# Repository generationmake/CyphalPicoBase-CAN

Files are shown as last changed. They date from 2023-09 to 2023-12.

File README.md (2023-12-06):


CyphalPicoBase/CAN
==================
Board for the Raspberry Pi Pico to connect via CAN using OpenCyphal and UCANPHY Micro.

You can buy one [here](https://cyphal.store/products/lxrobotics-cyphalpicobase-can) 💸.

<p align="center">
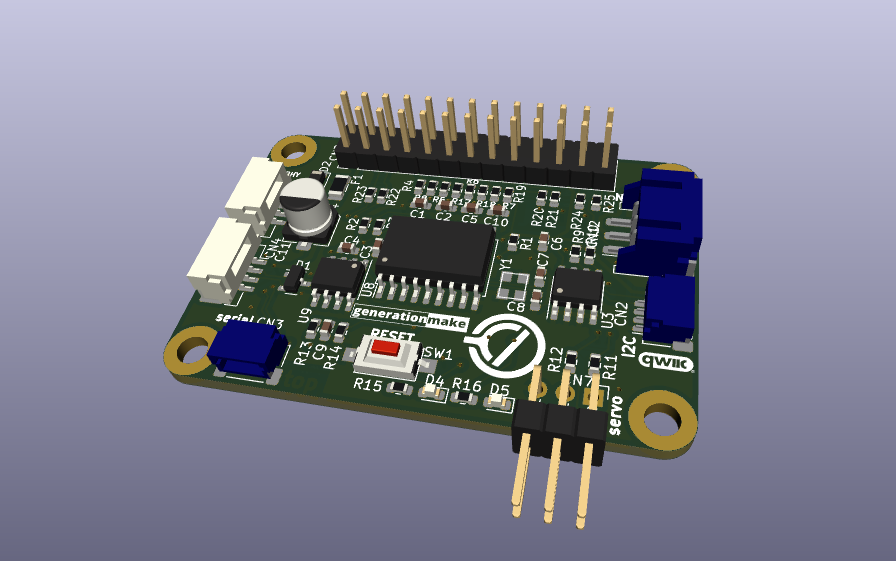
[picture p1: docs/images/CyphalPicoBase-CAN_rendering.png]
  
</p>

<p align="center">
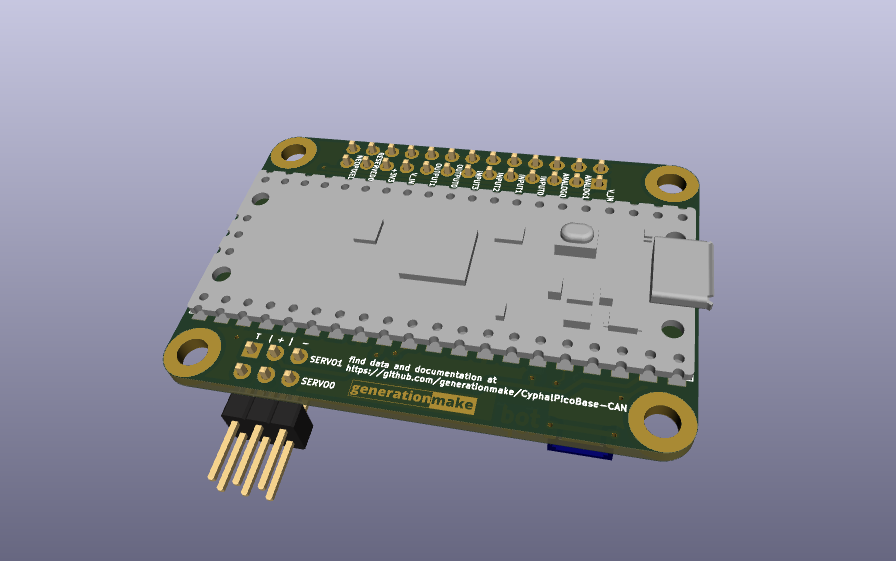
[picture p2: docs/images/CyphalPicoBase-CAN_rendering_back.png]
  
</p>

## Description

The CyphalPicoBase/CAN provides the following functions:
* CAN connectivity to a OpenCyphal CAN bus using a Microchip MCP2515 CAN controller ([datasheet](https://ww1.microchip.com/downloads/en/DeviceDoc/MCP2515-Stand-Alone-CAN-Controller-with-SPI-20001801J.pdf))
* Onboard I2C EEPROM to store settings
* measurement of CAN bus voltage using GP26
* onboard temperature measurement using the internal temperature sensor of the Raspberry Pi Pico
* two status LEDs (D4 and D5)
* Raspberry Pi Pico directly mounted on bottom layer
* connectors to several external functions (see list below)

## Firmware
* [CyphalPicoBase-CAN-firmware](https://github.com/107-systems/CyphalPicoBase-CAN-firmware): This is the default firmware for this board. It enables all basic functions

## Pin Usage and connectors

<p align="center">
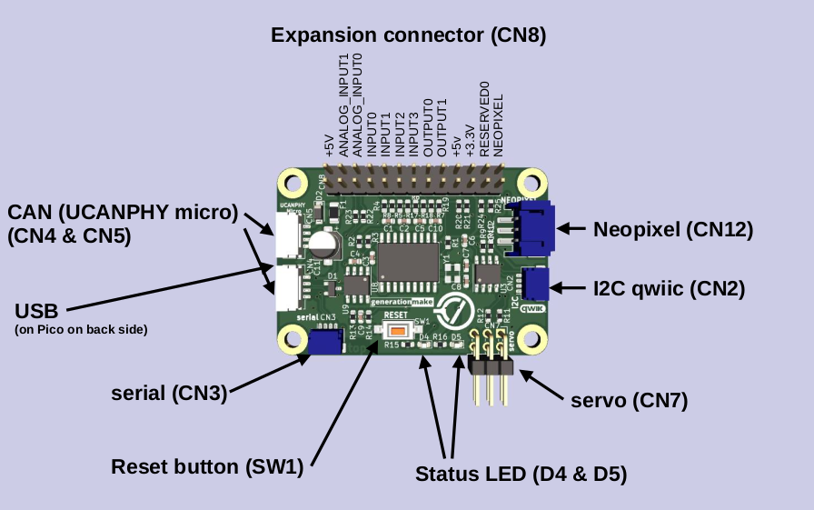
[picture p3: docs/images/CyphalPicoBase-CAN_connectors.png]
  
</p>

### Raspberry Pi Pico (CN1)

| **Pin** | **Pin Name** | **Signal** | **Description** |
|:---:|:---:|:---:|:---:|
| 1 | GP0 | UART0_TX | reserved for future use (GNSS) |
| 2 | GP1 | UART0_RX | reserved for future use (GNSS) |
| 3 | GND | GND | |
| 4 | GP2 | | |
| 5 | GP3 | | |
| 6 | GP4 | I2C0_SDA | for eeprom and qwiic connector |
| 7 | GP5 | I2C0_SCL | for eeprom and qwiic connector |
| 8 | GND | GND | |
| 9 | GP6 | GPI0 | input 0 |
| 10 | GP7 | GPI1 | input 1 |
| 11 | GP8 | GPI2 | input 2 |
| 12 | GP9 | GPI3 | input 3 |
| 13 | GND | GND | |
| 14 | GP10 | GPO0 | output 0 |
| 15 | GP11 | GPO1 | output 1 |
| 16 | GP12 | reserved | Neopixel |
| 17 | GP13 | reserved | radiation detector |
| 18 | GND | GND | |
| 19 | GP14 | SERVO0 | servo 0 |
| 20 | GP15 | SERVO1 | servo 1 |
| 21 | GP16 | SPI_MISO | SPI for MCP2515 |
| 22 | GP17 | MCP2515_CS | SPI for MCP2515 |
| 23 | GND | GND | |
| 24 | GP18 | SPI_CLK | SPI for MCP2515 |
| 25 | GP19 | SPI_MOSI | SPI for MCP2515 |
| 26 | GP20 | MCP2515_INT | interrupt for MCP2515 |
| 27 | GP21 | STATUS_LED2 | internal status LED 2 |
| 28 | GND | GND | |
| 29 | GP22 | STATUS_LED3 | internal status LED 3 |
| 30 | RUN | RESET | Reset for Board |
| 31 | GP26 | INPUT_VOLTAGE | measure input voltage |
| 32 | GP27 | ANALOG_INPUT0 | analog input |
| 33 | GND | GND | |
| 34 | GP28 | ANALOG_INPUT1 | analog input |
| 35 | ADC_VREF | | |
| 36 | 3V3 (OUT) | 3V3-rail | supply voltage for board |
| 37 | 3V3_EN | | |
| 38 | GND | GND | |
| 39 | VSYS | | |
| 40 | VBUS | 5V-rail | supply voltage for board |

## Pinout

### I2C (CN2)

compatible to the Sparkfun qwiic standard (https://www.sparkfun.com/qwiic). JST SH 1mm 4-pin.

| pin number | signal |
|:---:|:---:|
| 1 | GND |
| 2 | +3V3 |
| 3 | I2C_SDA |
| 4 | I2C_SCL |

### serial (CN3)

JST SH 1mm 4-pin.

| pin number | signal |
|:---:|:---:|
| 1 | GND |
| 2 | +3V3 |
| 3 | SER_TX |
| 4 | SER_RX |

### CAN (CN4 and CN5)

UCANPHY Micro connector, according to the UCANPHY_Specification (https://forum.opencyphal.org/t/cyphal-can-physical-layer-specification-v1-0/1471). JST GH 1.25mm 4-pin.

| pin number | signal |
|:---:|:---:|
| 1 | +5V |
| 2 | CANH |
| 3 | CANL |
| 4 | GND |

### servo connector (CN7)

This is a regular 0.1-inch pin header.

Standard RC servos can be directly plugged into this connector

| pin number | signal |
|:---:|:---:|
| 1 | servo0 |
| 2 | servo1 |
| 3 | +5V |
| 4 | +5V |
| 5 | GND |
| 6 | GND |

### input/output connector (CN8)

This is a regular 0.1-inch pin header.

| pin number | signal |
|:---:|:---:|
| 1 | +5V |
| 2 | GND |
| 3 | ANALOG_INPUT1 |
| 4 | GND |
| 5 | ANALOG_INPUT0 |
| 6 | GND |
| 7 | INPUT0 |
| 8 | GND |
| 9 | INPUT1 |
| 10 | GND |
| 11 | INPUT2 |
| 12 | GND |
| 13 | INPUT3 |
| 14 | GND |
| 15 | OUTPUT0 |
| 16 | GND |
| 17 | OUTPUT1 |
| 18 | GND |
| 19 | +5V |
| 20 | GND |
| 21 | +3.3V |
| 22 | GND |
| 23 | RESERVED0 |
| 24 | GND |
| 25 | NEOPIXEL |
| 26 | GND |

+5V can be fed over this connector to the servo connector (CN7) and the neopixel connector (CN12) if power supply over the CAN connector is not sufficicant.

### neopixel connector (CN12)

connector for Adafruit Neopixel RGB leds (https://learn.adafruit.com/adafruit-neopixel-uberguide/the-magic-of-neopixels). JST PH 2mm 3-pin.

| pin number | signal |
|:---:|:---:|
| 1 | neopixel |
| 2 | +5V |
| 3 | GND |

## enclosure

There exists a 3D printable enclosure to encapsulate the PCB.

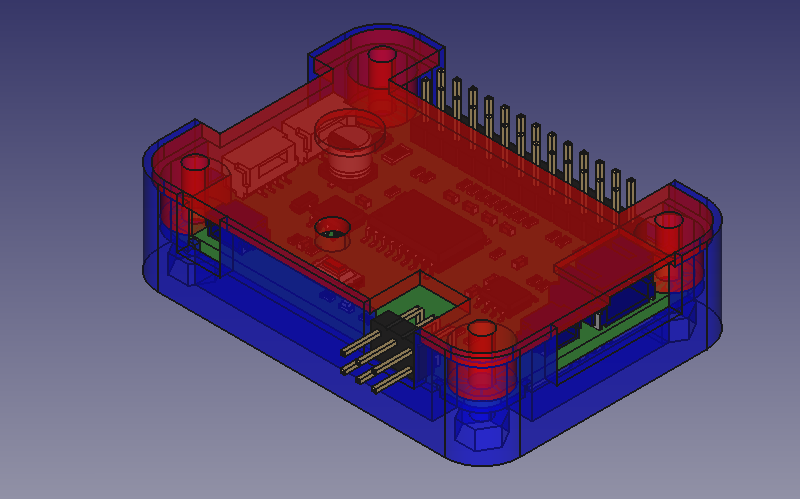
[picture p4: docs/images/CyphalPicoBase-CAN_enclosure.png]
CyphalPicoBase-CAN enclosure


## PCB
### Top
<p align="center">
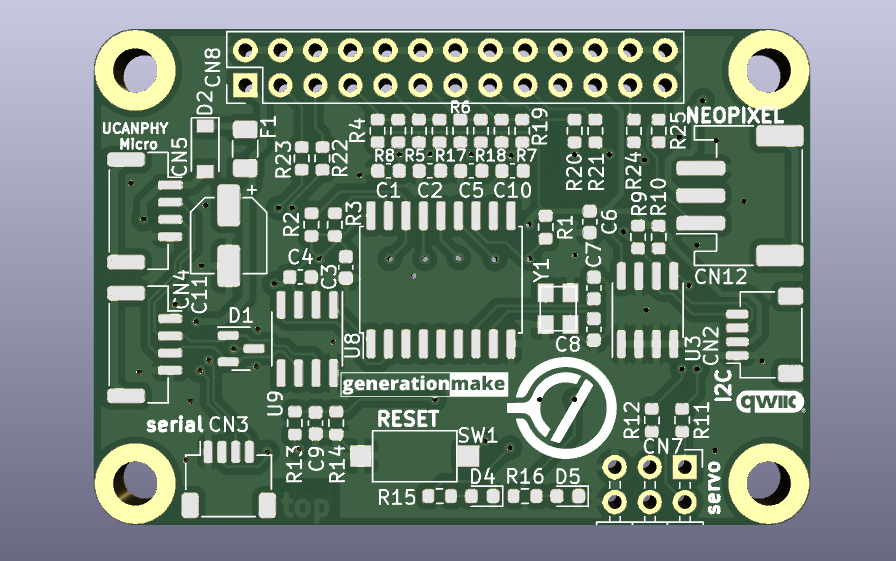
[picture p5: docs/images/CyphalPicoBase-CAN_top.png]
  
</p>

### Bottom
<p align="center">
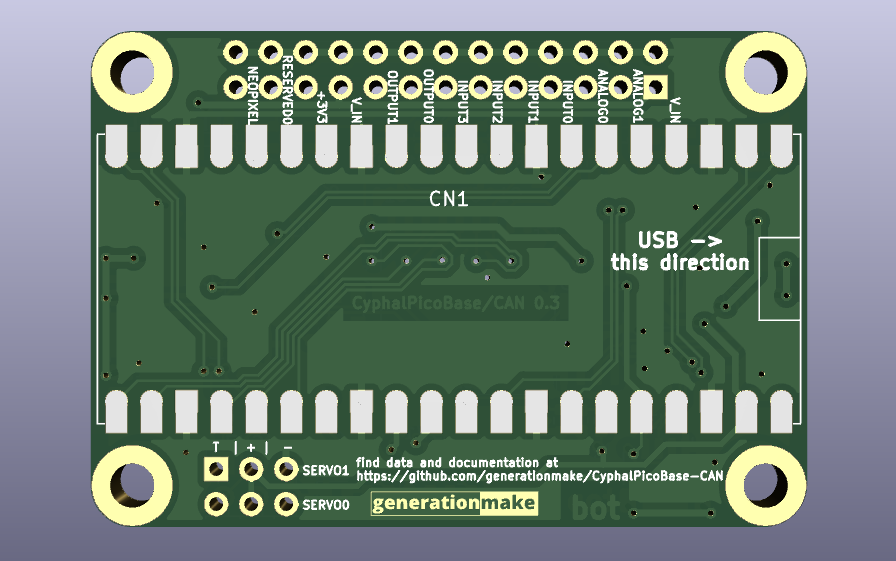
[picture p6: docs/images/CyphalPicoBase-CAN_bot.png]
  
</p>

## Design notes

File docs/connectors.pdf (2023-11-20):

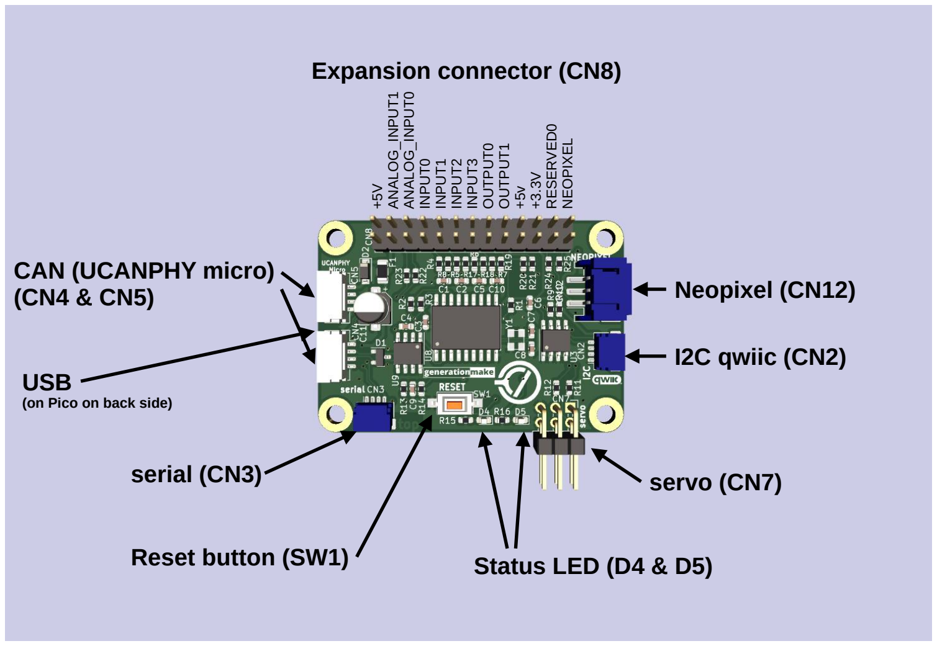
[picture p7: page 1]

Neopixel (CN12)

I2C qwiic (CN2)

CAN (UCANPHY micro)
(CN4 & CN5)

serial (CN3)

Reset button (SW1)

servo (CN7)

Status LED (D4 & D5)

USB

(on Pico on back side)

Expansion connector (CN8)

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
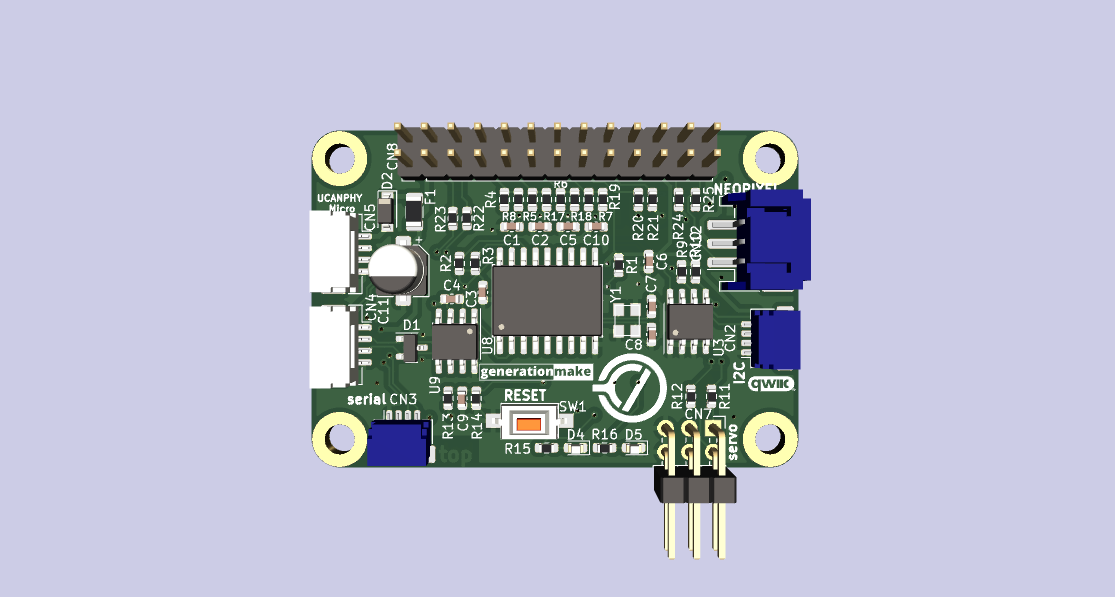
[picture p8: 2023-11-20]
docs/images/CyphalPicoBase-CAN_rendering_top.png

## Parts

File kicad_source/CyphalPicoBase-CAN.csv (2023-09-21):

Comment | Designator | Footprint | LCSC
100nF | C1,C2,C3,C4,C5,C6,C9,C10 | Capacitor_SMD:C_0603_1608Metric | C14663
100 uF / 6,3 V | C11 | Capacitor_SMD:CP_Elec_5x5.3 | C3001204
S3B-PH-SM4-TB | CN12 | Connector_JST:JST_PH_S3B-PH-SM4-TB_1x03-1MP_P2.00mm_Horizontal | C265101
SM04B-SRSS-TB | CN2,CN3 | Connector_JST:JST_SH_SM04B-SRSS-TB_1x04-1MP_P1.00mm_Horizontal | C160404
SM04B-GHS-TB | CN4,CN5 | Connector_JST:JST_GH_SM04B-GHS-TB_1x04-1MP_P1.25mm_Horizontal | C189895
MBR0530T | D2 | Diode_SMD:D_SOD-123 | C77336
NCD0603Y1 | D4 | LED_SMD:LED_0603_1608Metric | C84268
KT-0603R | D5 | LED_SMD:LED_0603_1608Metric | C2286
nSMD050-33V | F1 | Fuse:Fuse_1206_3216Metric | C70077
100R | R11,R12,R20,R21,R22,R23,R24,R25 | Resistor_SMD:R_0603_1608Metric | C22775
100k | R13 | Resistor_SMD:R_0603_1608Metric | C25803
3k3 | R15,R16 | Resistor_SMD:R_0603_1608Metric | C22978
10k | R1,R2,R3,R4,R5,R6,R7,R8,R9,R10,R14,R17,R18,R19 | Resistor_SMD:R_0603_1608Metric | C25804
PTS636 SM43 SMTR LFS | SW1 | Button_Switch_SMD:SW_SPST_CK_RS282G05A3 | C2800965
M24C64-RMN6TP | U3 | Package_SO:SOIC-8_3.9x4.9mm_P1.27mm | C79988
MCP2515T-I/SO | U8 | Package_SO:SOIC-18W_7.5x11.6mm_P1.27mm | C153782
SN65HVD230 | U9 | Package_SO:SOIC-8_3.9x4.9mm_P1.27mm | C12084
X322516MLB4SI | Y1 | crystals:Crystal_SMD_3.2x2.5mm_4Pad | C13738

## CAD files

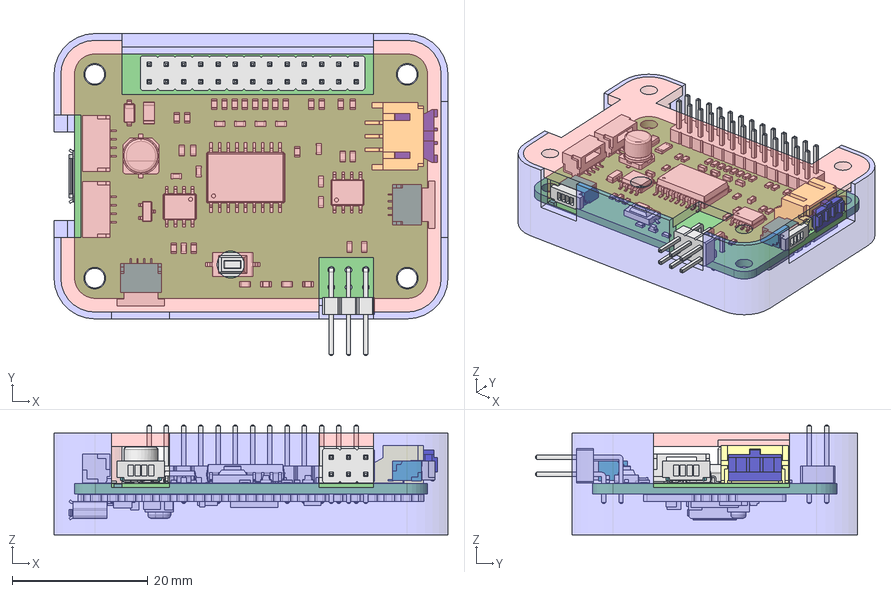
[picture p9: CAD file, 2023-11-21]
freecad_source/enclosure.FCStd
58.0 x 47.4 x 16.2 mm
bottom
top
CyphalPicoBase-CAN PCB
SHR-04V-S-B
SHR-04V-S-B001
PHR-3

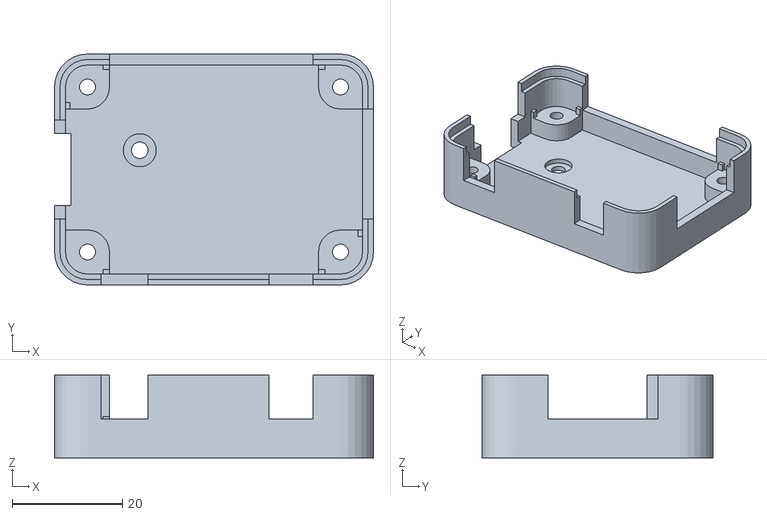
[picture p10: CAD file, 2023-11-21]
production_data/enclosure-bottom.stl
58.0 x 42.0 x 15.0

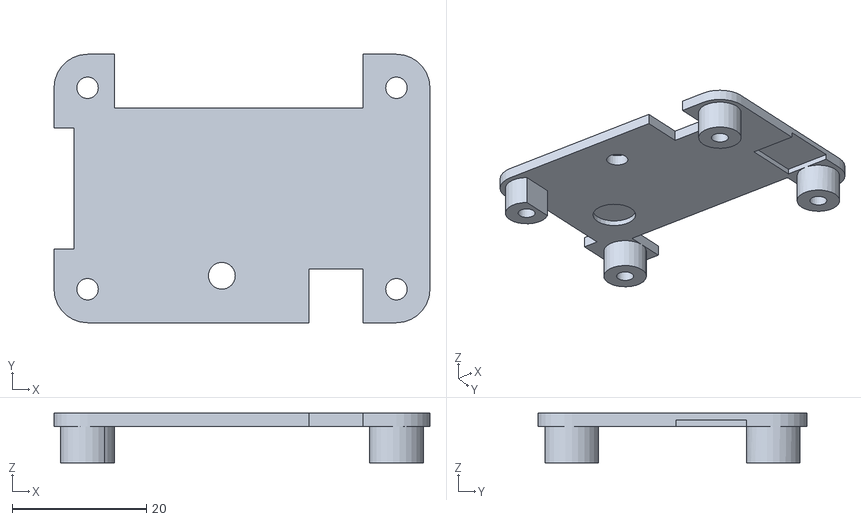
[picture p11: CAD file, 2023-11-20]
production_data/enclosure-top.stl
56.0 x 40.0 x 7.40

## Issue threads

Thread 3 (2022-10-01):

switch to SMD parts

generationmake, 2022-10-01:
switch to SMD parts for MCP2515 and crystal.
also switch to direct mounting of Raspberry Pi Pico. take care of the USB connector and place it on the edge of the board.

Closed 2023-01-04.

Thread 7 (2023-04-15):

add protection to CAN

generationmake, 2023-04-15:
Add some ESD protection to CAN bus.
For example with PESD2CAN on data lines.
https://assets.nexperia.com/documents/data-sheet/PESD2CAN.pdf
and TVS diode on bus voltage.

aentinger, 2023-04-16:
Let's discuss that. At one of my previous employers PESD2CAM added an unacceptable capacitance on the bus. Ultimately we got rid of them.

Closed 2023-09-21.

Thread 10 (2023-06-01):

Increase height of stand-offs inside bottom case by 1 mm to prevent BOOTSEL from accidentially being pressed

aentinger, 2023-06-01:
Adjust the rest of the design accordingly!

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

generationmake, 2023-06-01:
different approach: reduce thickness of the bottom plate in the area of the button by 1mm.

aentinger, 2023-06-02:
But make the area spacey enough, as any negative space always gets smaller during actual printing.

aentinger, 2023-06-04:
On further consideration: just increase the diameter of the already existing hole .

Closed 2023-06-18.

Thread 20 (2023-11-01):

[Feature Request] Replace SW1 w/ version w/ larger footprint

aentinger, 2023-11-01:
JLCPCB: C318938
https://jlcpcb.com/partdetail/XkbConnectivity-TS_1101_CW/C318938

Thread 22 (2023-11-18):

Feature Request: add cut-out for neopixel connector

aentinger, 2023-11-18:
Report by a customer:

I printed the CyphalPicoBase/CAN enclosure (using the file from GitHub) and the cover won't close, as the Neopixel connector is too tall for the cover spacers. You need to make a cut for the connector, I guess.

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

aentinger, 2023-11-18:
Or alternatively...

> A cut in the cover to allow the Neopixel to protrude somewhat into the cover, OR make spacers about 1 mm longer and increase the height of side walls of the enclosure by that same 1 mm.

Closed 2023-11-20.

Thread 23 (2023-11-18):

Feature Request: trim spacer on side of serial connector

aentinger, 2023-11-18:
Report by customer:

also, the cover spacer on the side of the serial connector is way too wide, so it's basically conflicting for space with the serial connector - would be good to trim the side of the spacer adjacent to the connector.

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

Closed 2023-11-20.

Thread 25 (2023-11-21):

[Feature Request] Increase size of outlet for Serial connector

aentinger, 2023-11-21:
Report by customer:

>Serial port hole is too narrow, connector won't fit through, I had to take the board pit, click it in, then put it back in.

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

Closed 2023-11-21.

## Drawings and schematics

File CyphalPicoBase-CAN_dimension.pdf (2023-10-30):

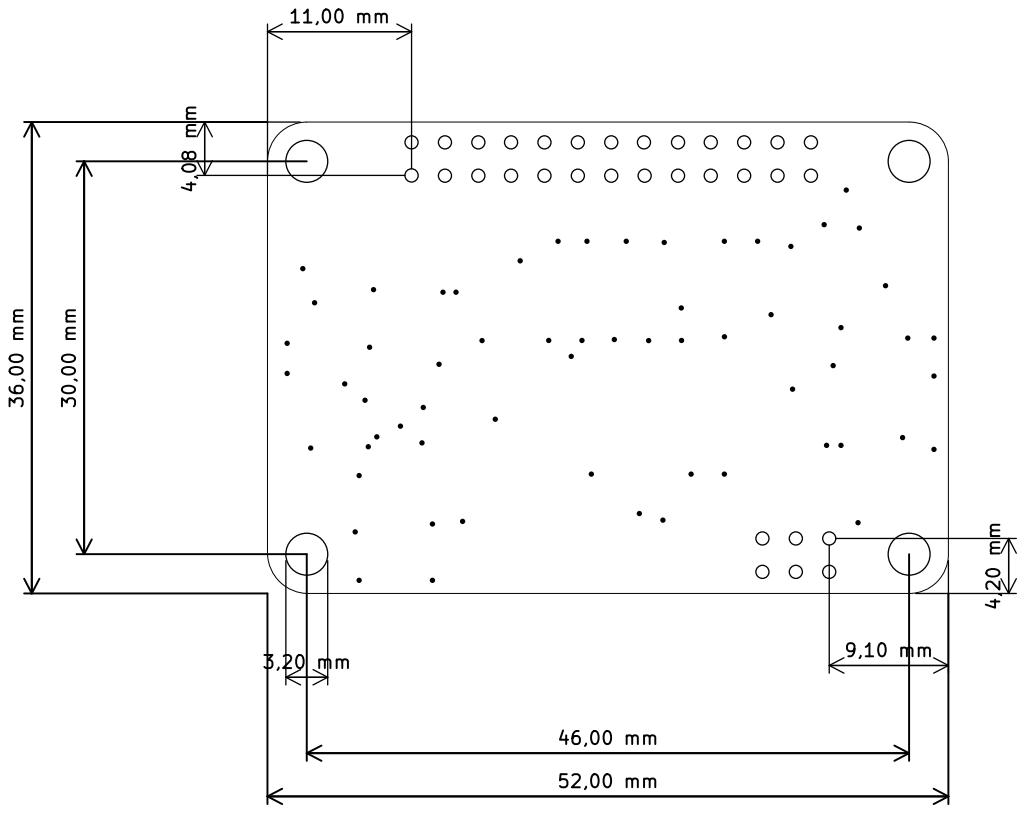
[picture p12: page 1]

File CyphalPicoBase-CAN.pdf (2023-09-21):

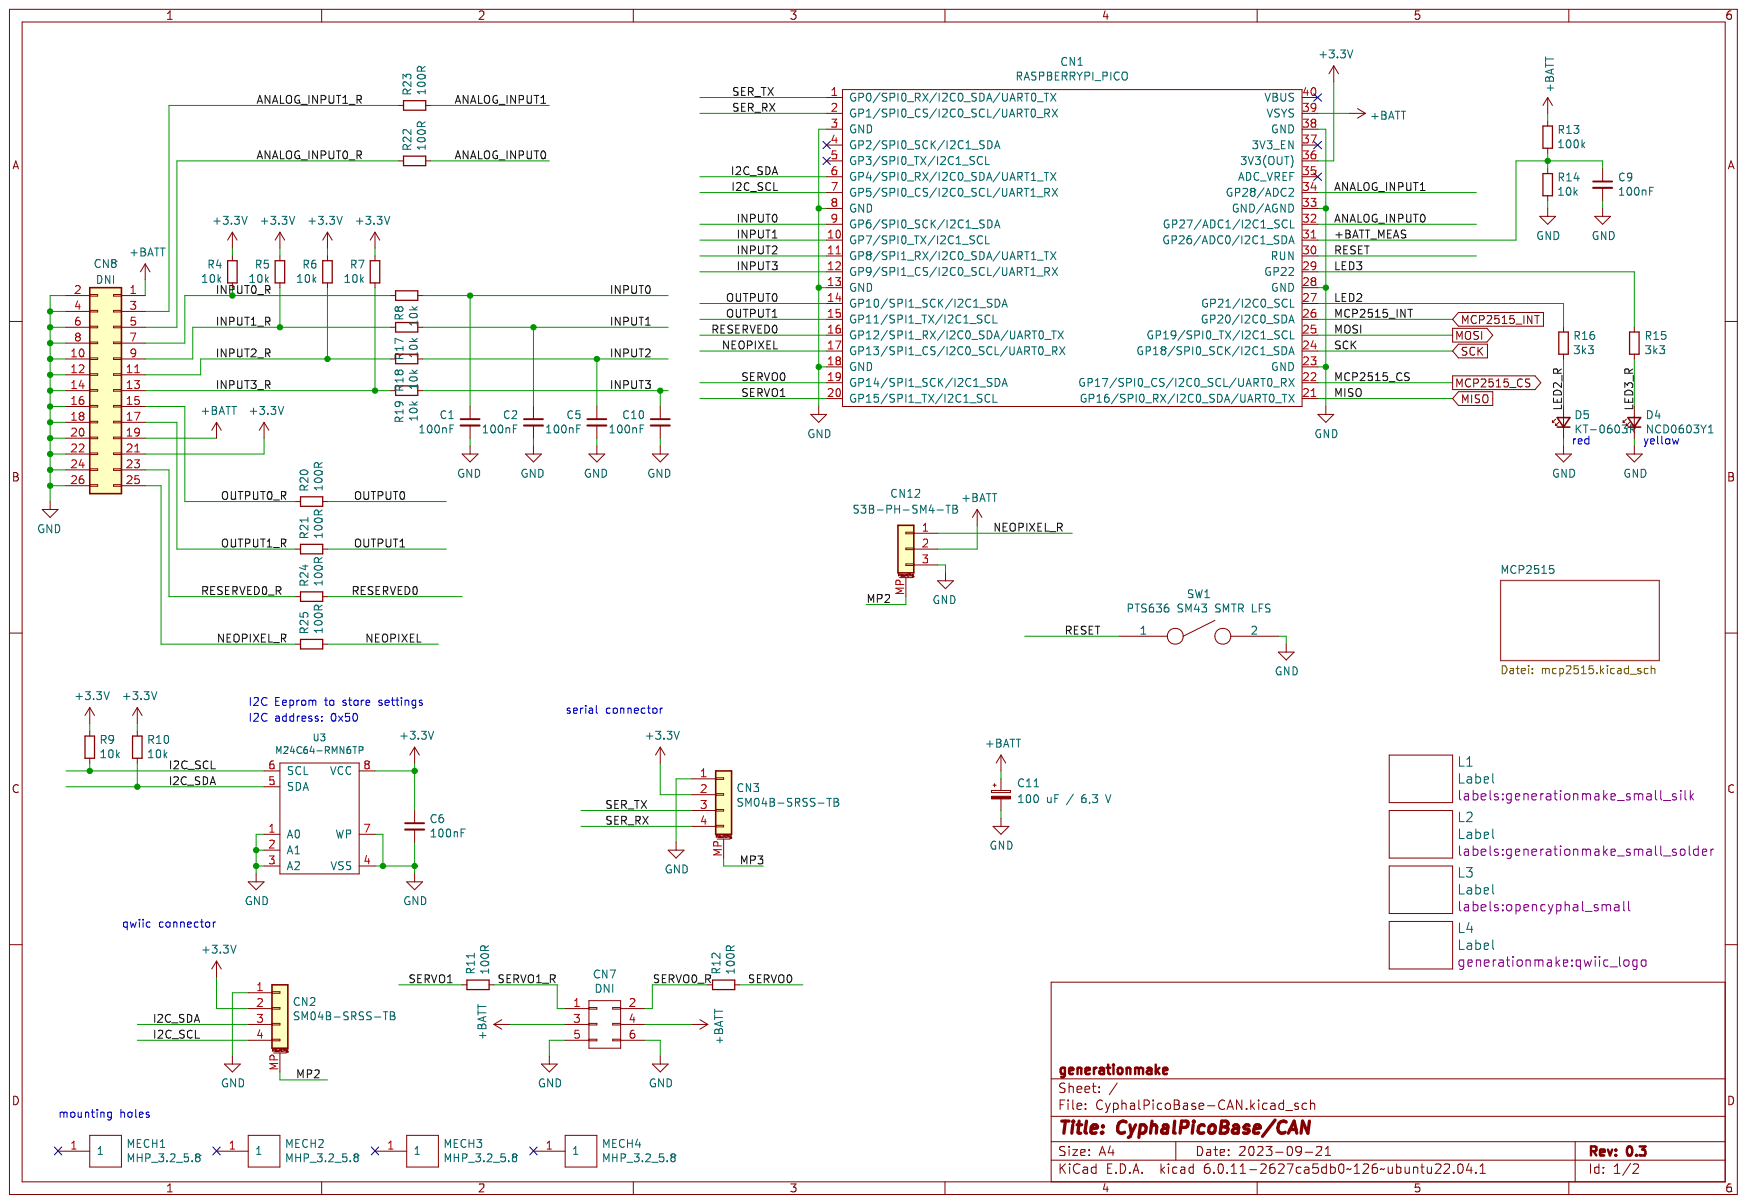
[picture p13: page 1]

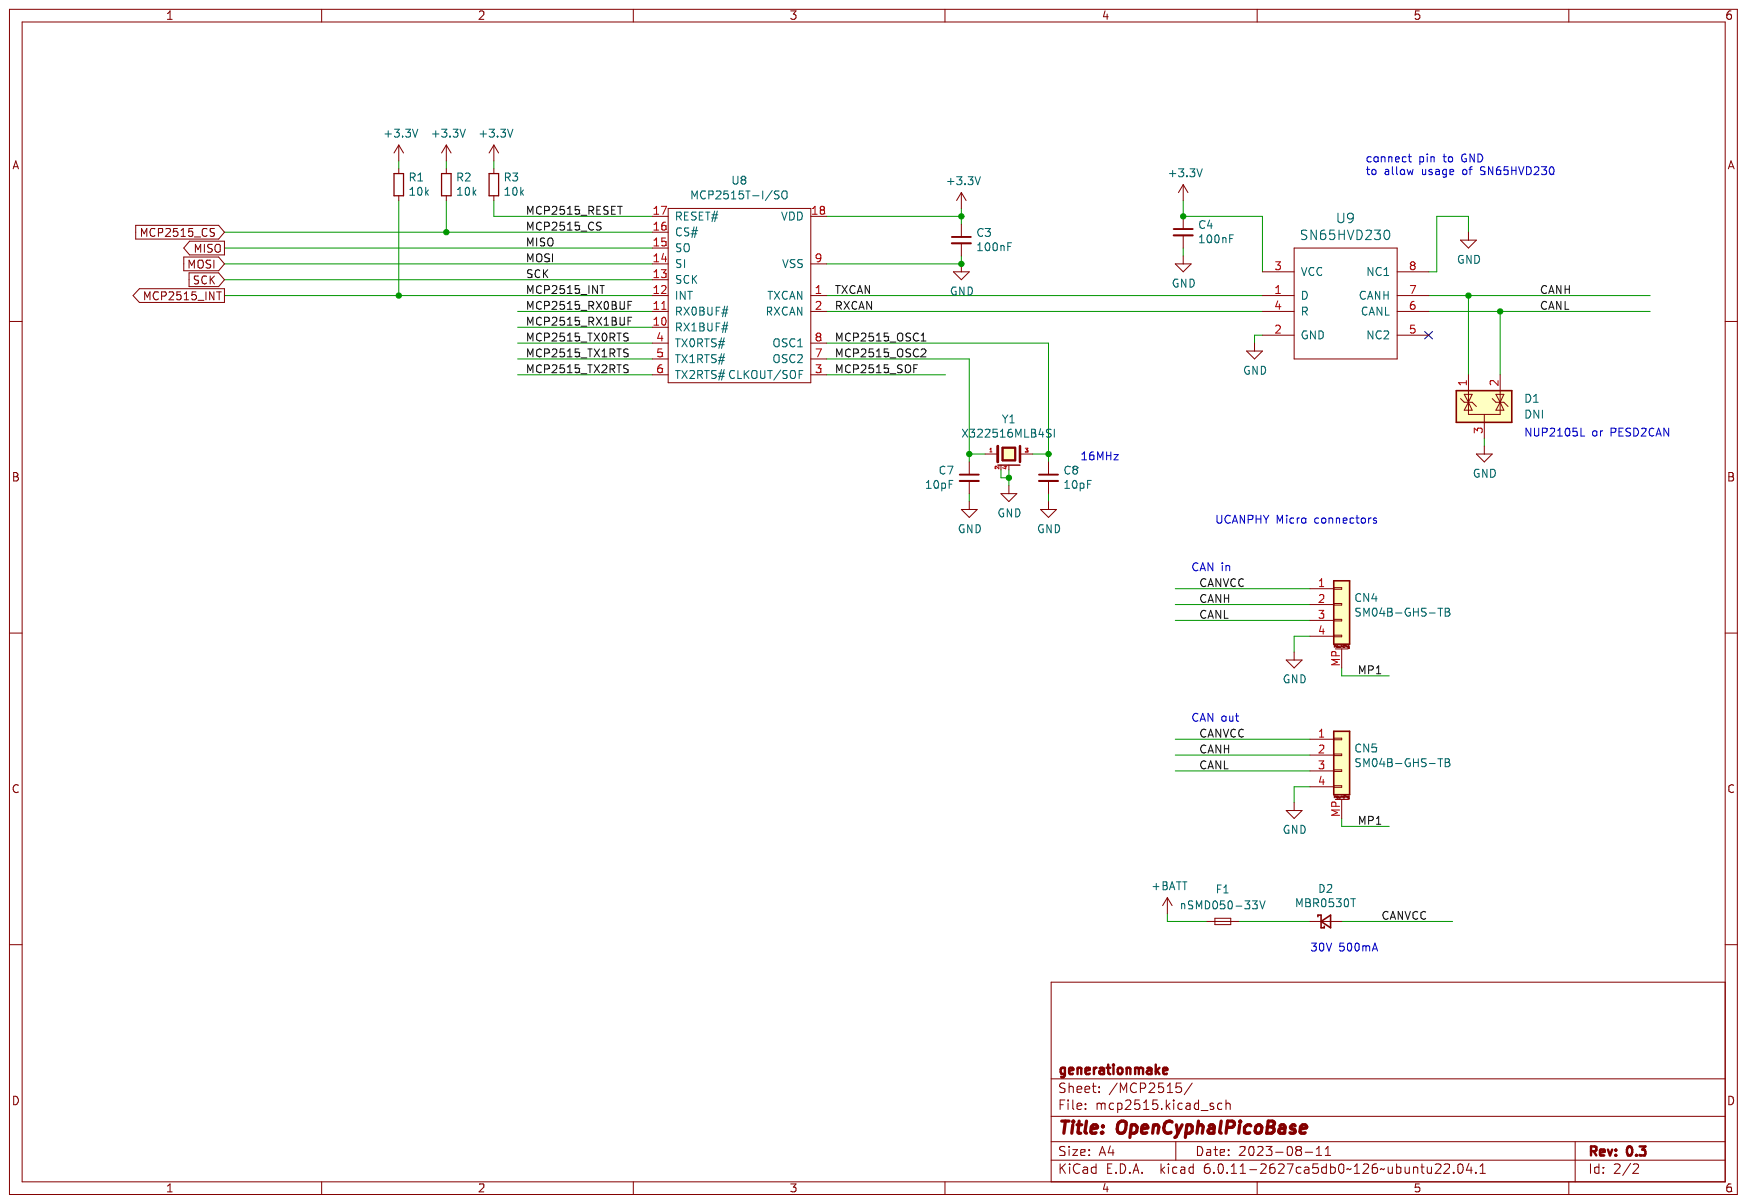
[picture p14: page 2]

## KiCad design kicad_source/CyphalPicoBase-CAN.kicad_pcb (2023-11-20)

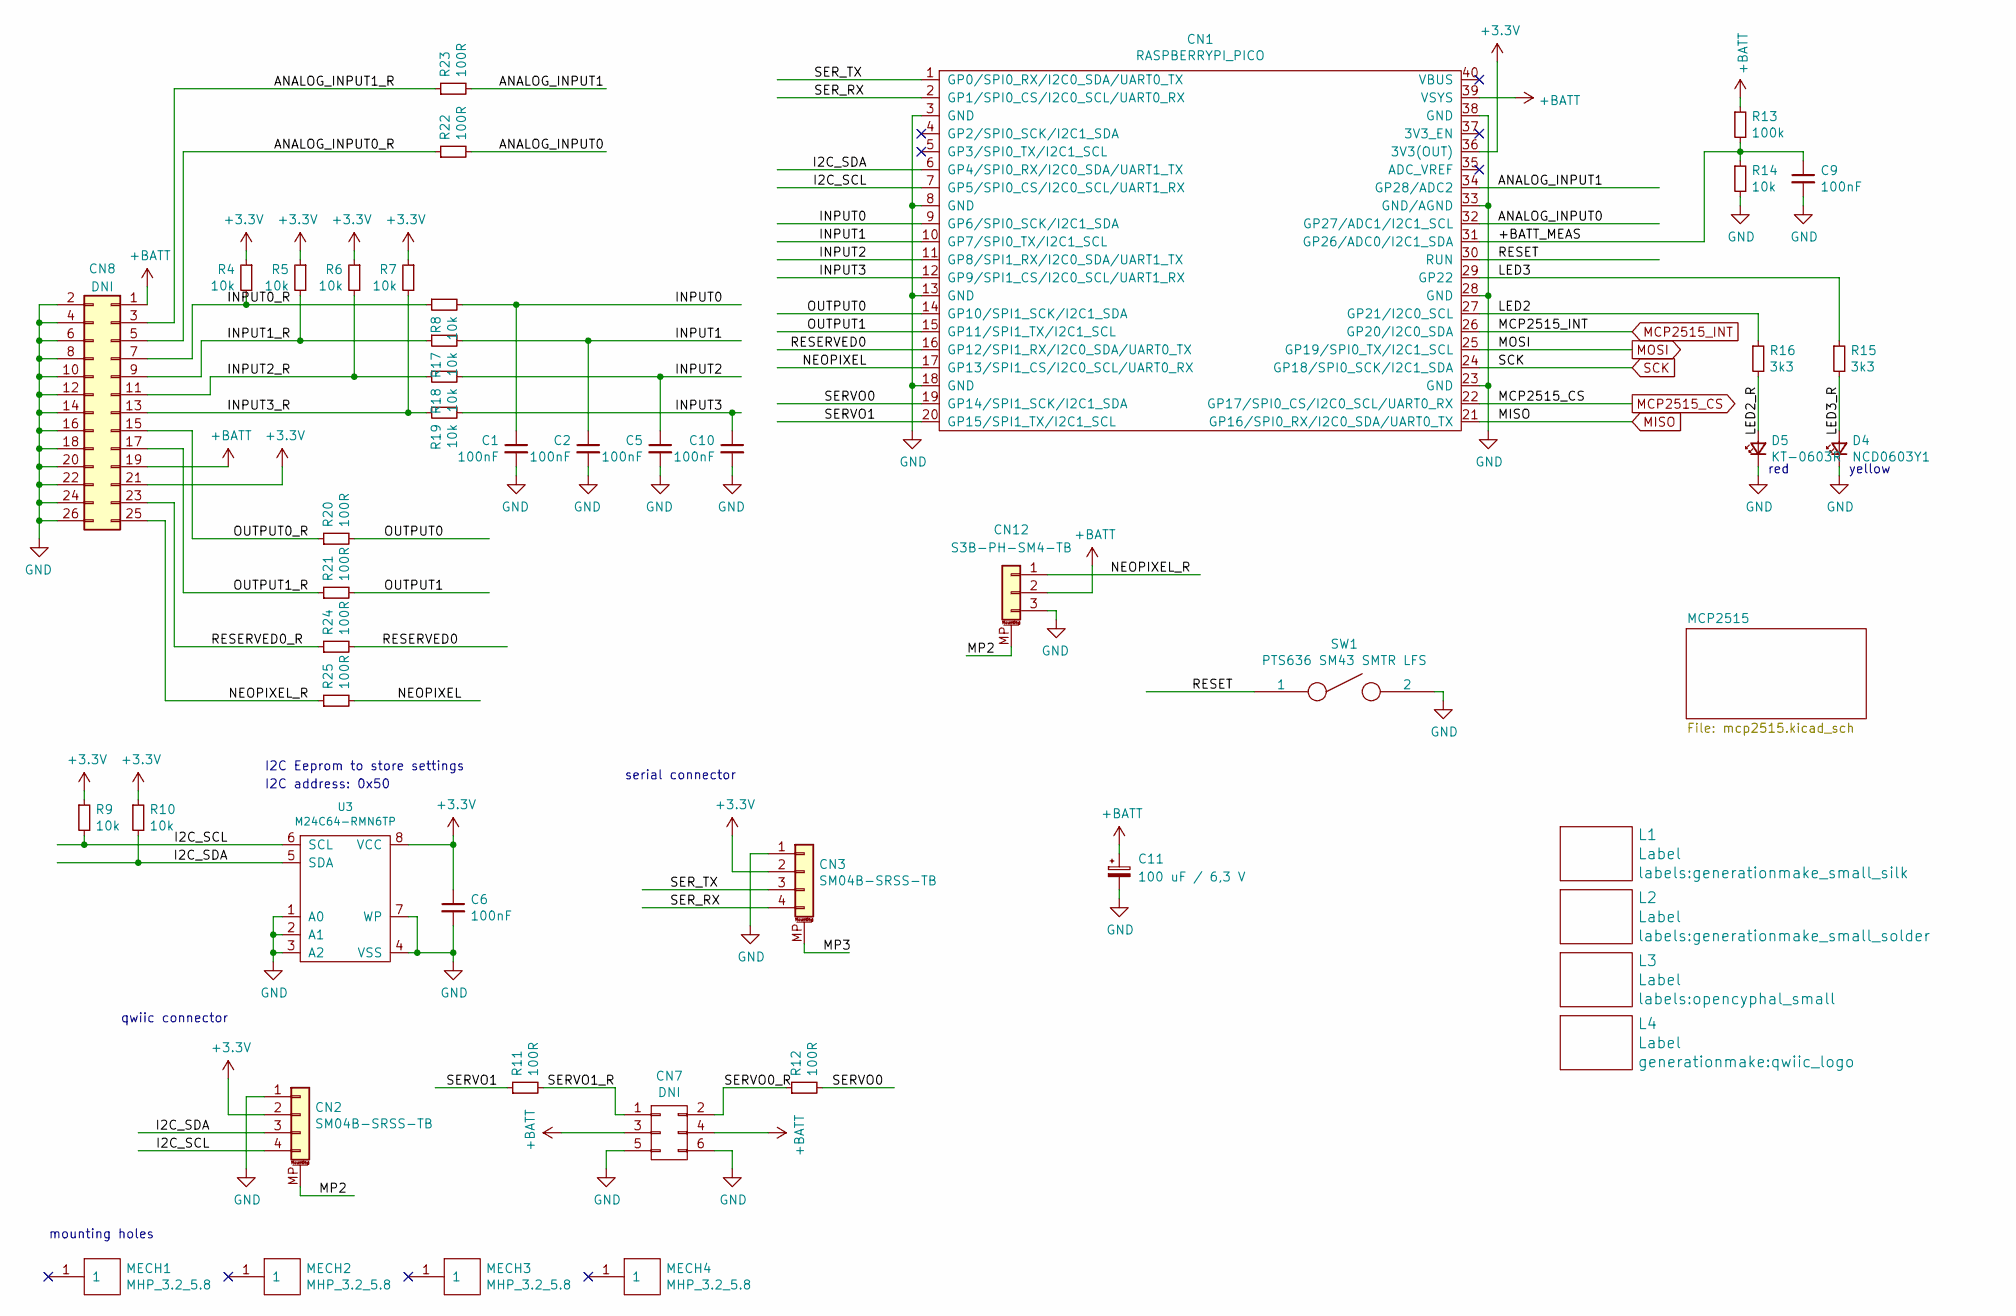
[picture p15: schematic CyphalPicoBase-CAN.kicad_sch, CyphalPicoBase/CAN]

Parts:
C1, C2, C5, C6, C9, C10: 100nF; C_0603_1608Metric; LCSC C14663
C11: 100 uF / 6,3 V; CP_Elec_5x5.3; LCSC C3001204
CN1: RASPBERRYPI_PICO; RASPI_PICO_SOLDER_Kopie
CN2, CN3: SM04B-SRSS-TB; JST_SH_SM04B-SRSS-TB_1x04-1MP_P1.00mm_Horizontal; LCSC C160404
CN7: DNI; PinHeader_2x03_P2.54mm_Horizontal
CN8: DNI; PinHeader_2x13_P2.54mm_Vertical
CN12: S3B-PH-SM4-TB; JST_PH_S3B-PH-SM4-TB_1x03-1MP_P2.00mm_Horizontal; LCSC C265101
D4: NCD0603Y1; LED_0603_1608Metric; LCSC C84268
D5: KT-0603R; LED_0603_1608Metric; LCSC C2286
L1: Label; generationmake_small_silk
L2: Label; generationmake_small_solder
L3: Label; opencyphal_small
L4: Label; qwiic_logo
MECH1, MECH2, MECH3, MECH4: MHP_3.2_5.8
R4, R5, R6, R7, R8, R9, R10, R14, R17, R18, R19: 10k; R_0603_1608Metric; LCSC C25804
R11, R12, R20, R21, R22, R23, R24, R25: 100R; R_0603_1608Metric; LCSC C22775
R13: 100k; R_0603_1608Metric; LCSC C25803
R15, R16: 3k3; R_0603_1608Metric; LCSC C22978
SW1: PTS636 SM43 SMTR LFS; SW_SPST_CK_RS282G05A3; LCSC C2800965
U3: M24C64-RMN6TP; SOIC-8_3.9x4.9mm_P1.27mm; LCSC C79988

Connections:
+3V3: C6.1, CN1.36 (3V3(OUT)), CN2.2, CN3.2, CN8.21, R4.1, R5.1, R6.1, R7.1, R9.1, R10.1, U3.8 (VCC); also elsewhere on the board
+BATT: C11.1, CN1.39 (VSYS), CN7.3, CN7.4, CN8.1, CN8.19, CN12.2, R13.1; also elsewhere on the board
/+BATT_MEAS: C9.1, CN1.31 (GP26/ADC0/I2C1_SDA), R13.2, R14.1
/ANALOG_INPUT0: CN1.32 (GP27/ADC1/I2C1_SCL), R22.2
/ANALOG_INPUT0_R: CN8.5, R22.1
/ANALOG_INPUT1: CN1.34 (GP28/ADC2), R23.2
/ANALOG_INPUT1_R: CN8.3, R23.1
/I2C_SCL: CN1.7 (GP5/SPI0_CS/I2C0_SCL/UART1_RX), CN2.4, R9.2, U3.6 (SCL)
/I2C_SDA: CN1.6 (GP4/SPI0_RX/I2C0_SDA/UART1_TX), CN2.3, R10.2, U3.5 (SDA)
/INPUT0: C1.1, CN1.9 (GP6/SPI0_SCK/I2C1_SDA), R8.2
/INPUT0_R: CN8.7, R4.2, R8.1
/INPUT1: C2.1, CN1.10 (GP7/SPI0_TX/I2C1_SCL), R17.2
/INPUT1_R: CN8.9, R5.2, R17.1
/INPUT2: C5.1, CN1.11 (GP8/SPI1_RX/I2C0_SDA/UART1_TX), R18.2
/INPUT2_R: CN8.11, R6.2, R18.1
/INPUT3: C10.1, CN1.12 (GP9/SPI1_CS/I2C0_SCL/UART1_RX), R19.2
/INPUT3_R: CN8.13, R7.2, R19.1
/LED2: CN1.27 (GP21/I2C0_SCL), R16.1
/LED2_R: D5.2 (A), R16.2
/LED3: CN1.29 (GP22), R15.1
/LED3_R: D4.2 (A), R15.2
/MP2: CN2.MP (MountPin), CN12.MP (MountPin)
/MP3: CN3.MP (MountPin)
/NEOPIXEL: CN1.17 (GP13/SPI1_CS/I2C0_SCL/UART0_RX), R25.2
/NEOPIXEL_R: CN8.25, CN12.1, R25.1
/OUTPUT0: CN1.14 (GP10/SPI1_SCK/I2C1_SDA), R20.2
/OUTPUT0_R: CN8.15, R20.1
/OUTPUT1: CN1.15 (GP11/SPI1_TX/I2C1_SCL), R21.2
/OUTPUT1_R: CN8.17, R21.1
/RESERVED0: CN1.16 (GP12/SPI1_RX/I2C0_SDA/UART0_TX), R24.2
/RESERVED0_R: CN8.23, R24.1
/RESET: CN1.30 (RUN), SW1.1
/SERVO0: CN1.19 (GP14/SPI1_SCK/I2C1_SDA), R12.2
/SERVO0_R: CN7.2, R12.1
/SERVO1: CN1.20 (GP15/SPI1_TX/I2C1_SCL), R11.1
/SERVO1_R: CN7.1, R11.2
/SER_RX: CN1.2 (GP1/SPI0_CS/I2C0_SCL/UART0_RX), CN3.4
/SER_TX: CN1.1 (GP0/SPI0_RX/I2C0_SDA/UART0_TX), CN3.3
GND: C1.2, C2.2, C5.2, C6.2, C9.2, C10.2, C11.2, CN1.3 (GND), CN1.8 (GND), CN1.13 (GND), CN1.18 (GND), CN1.23 (GND), CN1.28 (GND), CN1.33 (GND/AGND), CN1.38 (GND), CN2.1, CN3.1, CN7.5, CN7.6, CN8.2, CN8.4, CN8.6, CN8.8, CN8.10, CN8.12, CN8.14, CN8.16, CN8.18, CN8.20, CN8.22, CN8.24, CN8.26, CN12.3, D4.1 (K), D5.1 (K), R14.2, SW1.2, U3.1 (A0), U3.2 (A1), U3.3 (A2), U3.4 (VSS), U3.7 (WP); also elsewhere on the board
MCP2515_CS: CN1.22 (GP17/SPI0_CS/I2C0_SCL/UART0_RX); also elsewhere on the board
MCP2515_INT: CN1.26 (GP20/I2C0_SDA); also elsewhere on the board
MISO: CN1.21 (GP16/SPI0_RX/I2C0_SDA/UART0_TX); also elsewhere on the board
MOSI: CN1.25 (GP19/SPI0_TX/I2C1_SCL); also elsewhere on the board
SCK: CN1.24 (GP18/SPI0_SCK/I2C1_SDA); also elsewhere on the board

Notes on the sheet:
yellow
serial connector
qwiic connector
mounting holes
red
I2C address: 0x50
I2C Eeprom to store settings

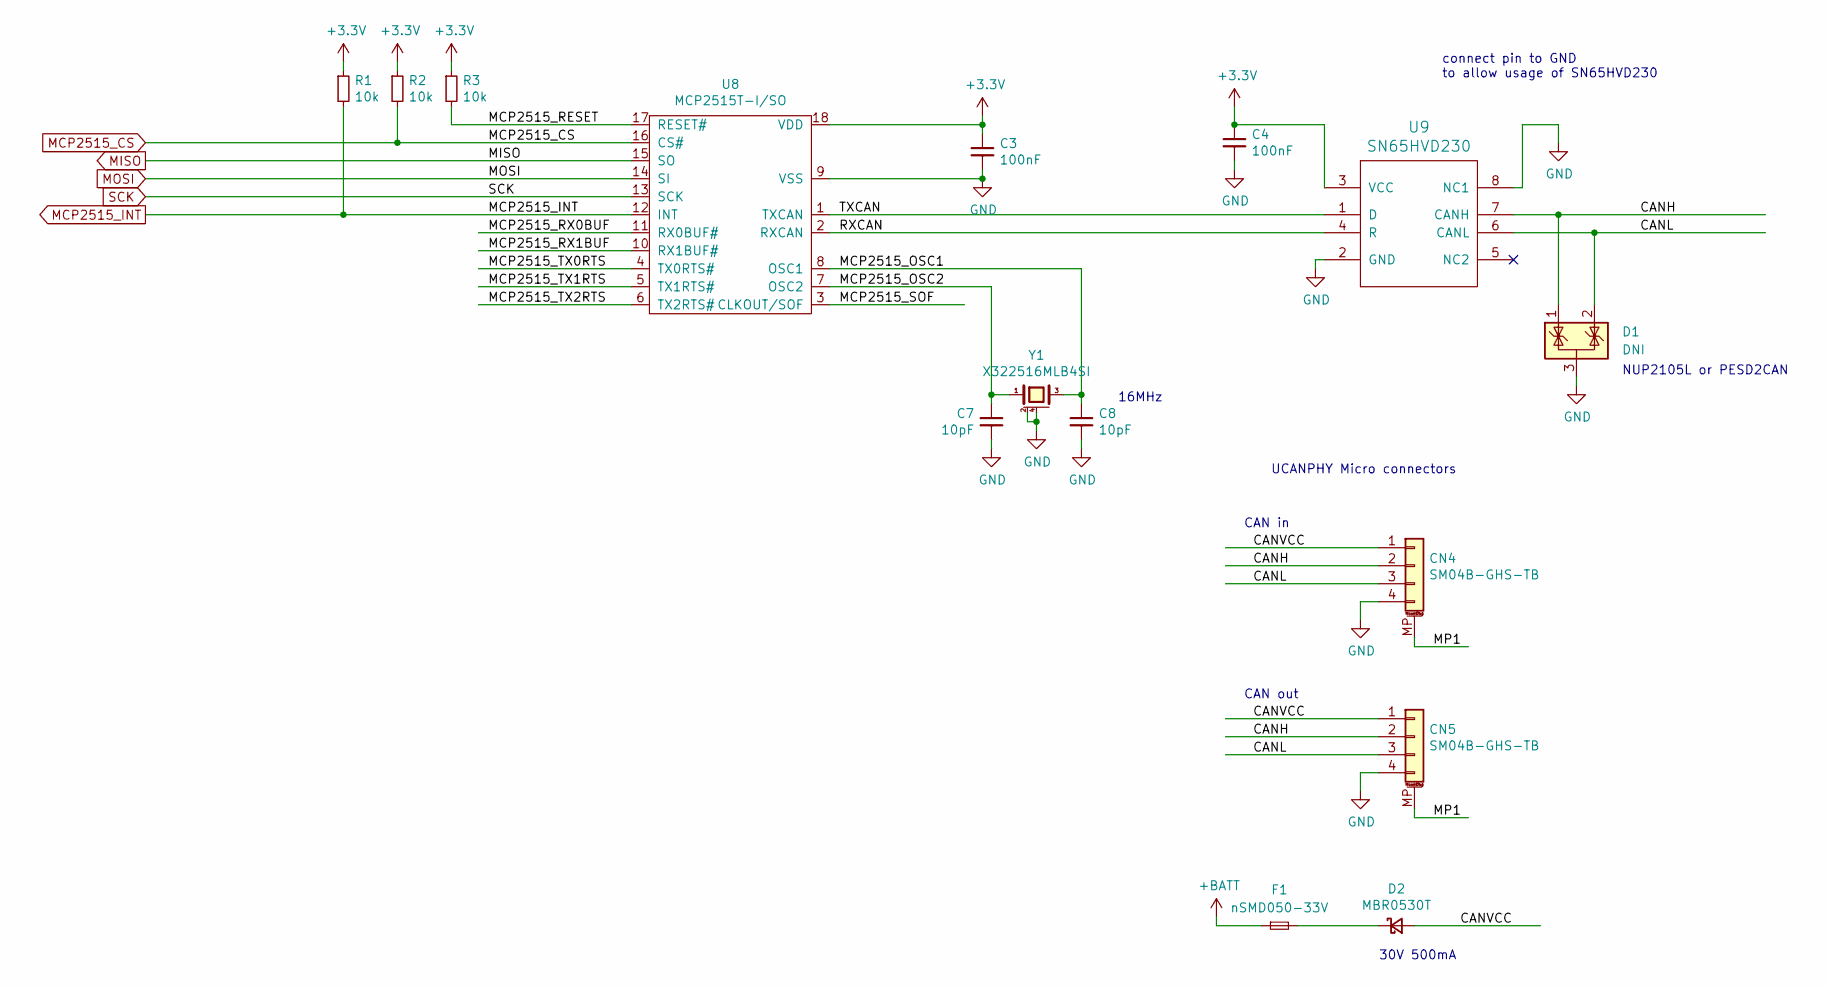
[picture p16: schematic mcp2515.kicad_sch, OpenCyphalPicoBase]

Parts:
C3, C4: 100nF; C_0603_1608Metric; LCSC C14663
C7, C8: 10pF; C_0603_1608Metric; LCSC C1634
CN4, CN5: SM04B-GHS-TB; JST_GH_SM04B-GHS-TB_1x04-1MP_P1.25mm_Horizontal; LCSC C189895
D1: DNI; SOT-23
D2: MBR0530T; D_SOD-123; LCSC C77336
F1: nSMD050-33V; Fuse_1206_3216Metric; LCSC C70077
R1, R2, R3: 10k; R_0603_1608Metric; LCSC C25804
U8: MCP2515T-I/SO; SOIC-18W_7.5x11.6mm_P1.27mm; LCSC C153782
U9: SN65HVD230; SOIC-8_3.9x4.9mm_P1.27mm; LCSC C12084
Y1: X322516MLB4SI; Crystal_SMD_3.2x2.5mm_4Pad; LCSC C13738

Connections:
+3V3: C3.1, C4.1, R1.1, R2.1, R3.1, U8.18 (VDD), U9.3 (VCC); also elsewhere on the board
+BATT: F1.1; also elsewhere on the board
/MCP2515/CANH: CN4.2, CN5.2, D1.1 (K), U9.7 (CANH)
/MCP2515/CANL: CN4.3, CN5.3, D1.2 (K), U9.6 (CANL)
/MCP2515/CANVCC: CN4.1, CN5.1, D2.2 (A)
/MCP2515/MCP2515_OSC1: C8.1, U8.8 (OSC1), Y1.3
/MCP2515/MCP2515_OSC2: C7.1, U8.7 (OSC2), Y1.1
/MCP2515/MCP2515_RESET: R3.2, U8.17 (RESET#)
/MCP2515/MCP2515_RX0BUF: U8.11 (RX0BUF#)
/MCP2515/MCP2515_RX1BUF: U8.10 (RX1BUF#)
/MCP2515/MCP2515_SOF: U8.3 (CLKOUT/SOF)
/MCP2515/MCP2515_TX0RTS: U8.4 (TX0RTS#)
/MCP2515/MCP2515_TX1RTS: U8.5 (TX1RTS#)
/MCP2515/MCP2515_TX2RTS: U8.6 (TX2RTS#)
/MCP2515/MP1: CN4.MP (MountPin), CN5.MP (MountPin)
/MCP2515/RXCAN: U8.2 (RXCAN), U9.4 (R)
/MCP2515/TXCAN: U8.1 (TXCAN), U9.1 (D)
GND: C3.2, C4.2, C7.2, C8.2, CN4.4, CN5.4, D1.3 (A), U8.9 (VSS), U9.2 (GND), U9.8 (NC1), Y1.2 (case), Y1.4 (case); also elsewhere on the board
MCP2515_CS: R2.2, U8.16 (CS#); also elsewhere on the board
MCP2515_INT: R1.2, U8.12 (INT); also elsewhere on the board
MISO: U8.15 (SO); also elsewhere on the board
MOSI: U8.14 (SI); also elsewhere on the board
unnamed: D2.1 (K), F1.2
SCK: U8.13 (SCK); also elsewhere on the board

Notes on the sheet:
16MHz
NUP2105L or PESD2CAN
connect pin to GND to allow usage of SN65HVD230
UCANPHY Micro connectors
30V 500mA
CAN in
CAN out

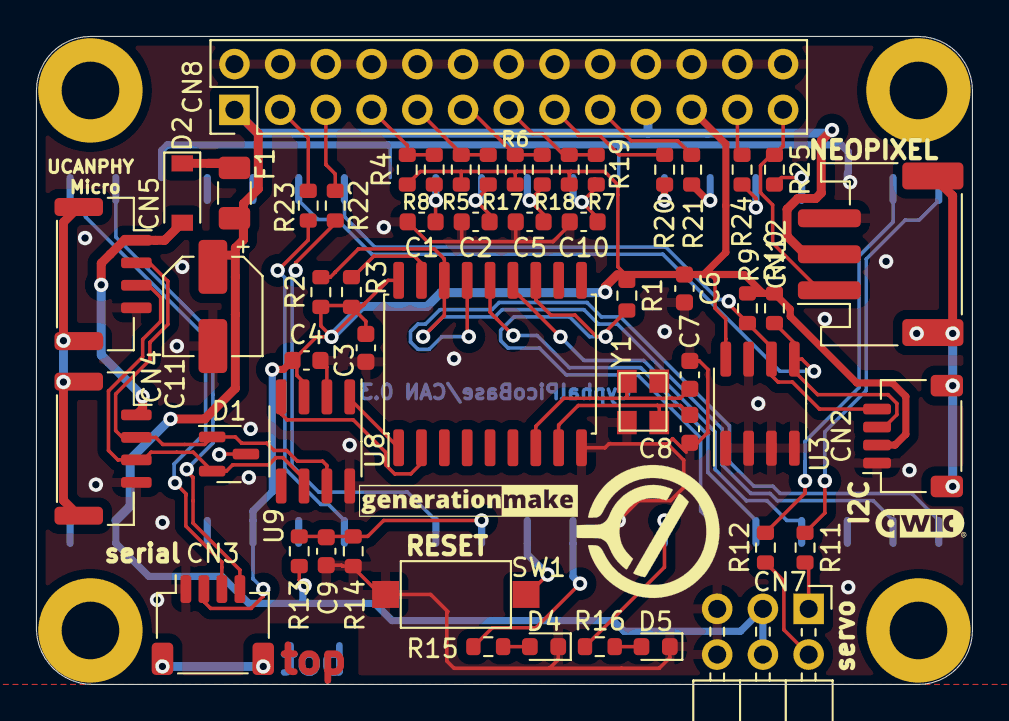
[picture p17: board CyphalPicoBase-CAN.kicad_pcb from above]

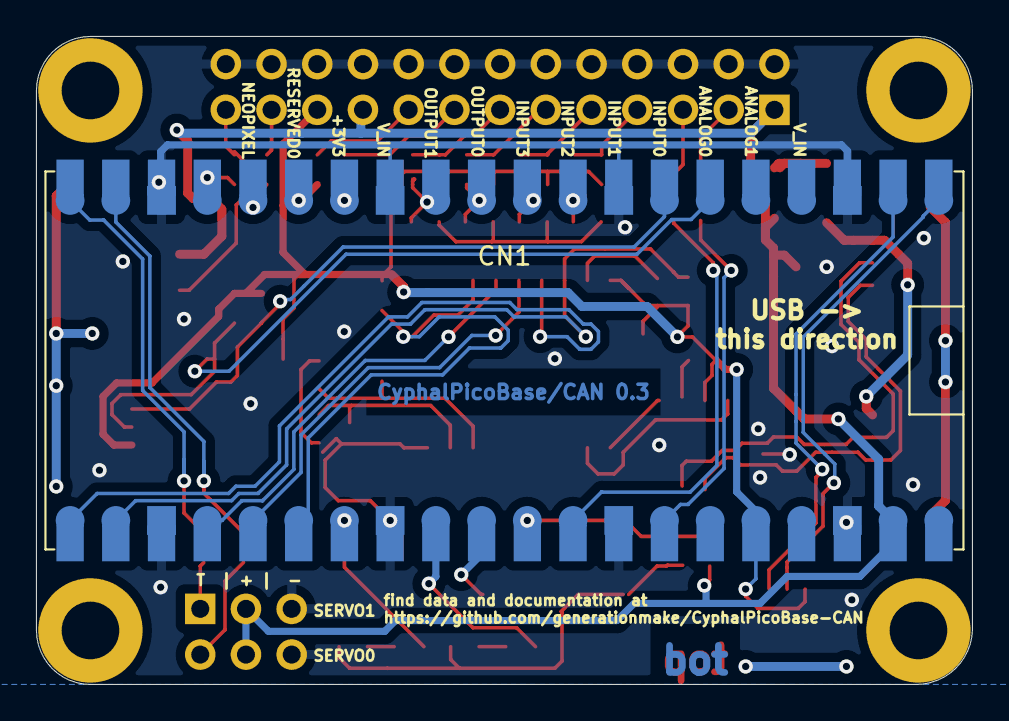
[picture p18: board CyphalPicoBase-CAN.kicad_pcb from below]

Board: 2 copper layers, 52.0 x 36.0 mm, 62 parts (2 on the bottom side), 53 nets.

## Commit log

2022-06-06 added first draft of schematic and layout
    [OpenCyphalPicoBase.kicad_pcb, OpenCyphalPicoBase.sch, mcp2515.sch]
2022-06-06 added schematic pdf and images
    [OpenCyphalPicoBase.kicad_pcb]
2022-06-08 updated layout, added connectors for input and output
    [OpenCyphalPicoBase.kicad_pcb, OpenCyphalPicoBase.sch]
2022-06-09 added screw terminals for CAN
    [OpenCyphalPicoBase.kicad_pcb, mcp2515.sch]
2022-06-09 added solder pads for raspberry pi pico
    [OpenCyphalPicoBase.kicad_pcb, OpenCyphalPicoBase.sch]
2022-06-09 updated schematic pdf and images, made DRC
    [OpenCyphalPicoBase.kicad_pcb, OpenCyphalPicoBase.sch]
2022-10-09 saved project with kicad 6
    [OpenCyphalPicoBase.kicad_pcb, OpenCyphalPicoBase.kicad_sch, OpenCyphalPicoBase.sch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]
2022-10-09 removed some tht parts
    [OpenCyphalPicoBase.kicad_pcb, OpenCyphalPicoBase.kicad_sch, mcp2515.kicad_sch]
2022-10-21 switched Raspberry Pi Pico to direct solder only
    [OpenCyphalPicoBase.kicad_pcb, OpenCyphalPicoBase.kicad_sch]
2022-10-21 reworked library references
    [OpenCyphalPicoBase.kicad_pcb, OpenCyphalPicoBase.kicad_sch, mcp2515.kicad_sch]
2022-10-22 changed some connectors
    [OpenCyphalPicoBase.kicad_pcb, OpenCyphalPicoBase.kicad_sch]
2022-10-22 added NeoPixel connector, updated layout
    [OpenCyphalPicoBase.kicad_pcb, OpenCyphalPicoBase.kicad_sch]
2022-10-23 fixed some drc errors
    [OpenCyphalPicoBase.kicad_pcb]
2022-10-23 switched servos to +BATT to power them from CAN bus
    [OpenCyphalPicoBase.kicad_pcb, OpenCyphalPicoBase.kicad_sch]
2022-10-23 updated schematic pdf
2022-10-25 added poly fuse
    [OpenCyphalPicoBase.kicad_pcb, OpenCyphalPicoBase.kicad_sch, mcp2515.kicad_sch]
2022-10-26 added capacitor on +BATT
    [OpenCyphalPicoBase.kicad_pcb, OpenCyphalPicoBase.kicad_sch]
2022-10-26 added 3d model of raspberry pi pico
    [OpenCyphalPicoBase.kicad_pcb]
2022-10-26 updated DRC
    [OpenCyphalPicoBase.kicad_pcb]
2023-01-08 added step file and freecad project
    [OpenCyphalPicoBase.kicad_pcb, enclosure.FCStd]
2023-01-09 updated enclosure
    [enclosure.FCStd]
2023-01-09 added 3d print production data
    [enclosure-bottom.stl, enclosure-top.stl, enclosure.FCStd]
2023-01-21 added screw holes
    [enclosure.FCStd]
2023-01-21 updated production data
    [enclosure-bottom.stl, enclosure-top.stl]
2023-01-24 Adding Prusa Slicer projects and GCode.
    [enclosure-bottom.3mf, enclosure-top.3mf]
2023-01-25 increased the cut out for the USB connector
    [enclosure-bottom.stl, enclosure.FCStd]
2023-04-16 clearified some part numbers
    [OpenCyphalPicoBase.kicad_pcb, OpenCyphalPicoBase.kicad_sch, mcp2515.kicad_sch]
2023-06-04 made more space for boot sel button
    [enclosure-bottom.stl, enclosure.FCStd]
2023-06-04 added small standoffs to position PCB
    [enclosure-bottom.stl, enclosure.FCStd]
2023-08-03 generated gerber files
    [OpenCyphalPicoBase-B_Cu.gbl, OpenCyphalPicoBase-B_Mask.gbs, OpenCyphalPicoBase-B_Paste.gbp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]
2023-08-03 added gerber zip file
2023-08-03 added some JLCPCB part numbers and BOM
    [OpenCyphalPicoBase.csv, OpenCyphalPicoBase.kicad_sch, mcp2515.kicad_sch]
2023-08-03 added placement file
    [OpenCyphalPicoBase-top-pos.csv]
2023-08-06 added missing JLCPCB part numbers
    [OpenCyphalPicoBase.csv, OpenCyphalPicoBase.kicad_sch, mcp2515.kicad_sch]
2023-08-06 switched to JLCPCB basic parts where possible
    [OpenCyphalPicoBase.csv, OpenCyphalPicoBase.kicad_sch, mcp2515.kicad_sch]
2023-08-08 combined CN6, CN8 and CN11 into one connector
    [OpenCyphalPicoBase.kicad_pcb, OpenCyphalPicoBase.kicad_sch, mcp2515.kicad_sch]
2023-08-08 removed C12, added CAN protection, updated schematic
    [OpenCyphalPicoBase.kicad_pcb, OpenCyphalPicoBase.kicad_sch, mcp2515.kicad_sch]
2023-08-09 added qwiic logo, made DRC
    [OpenCyphalPicoBase.kicad_pcb, OpenCyphalPicoBase.kicad_sch, mcp2515.kicad_sch]
2023-08-09 generated gerber and production data
    [OpenCyphalPicoBase-B_Cu.gbl, OpenCyphalPicoBase-B_Mask.gbs, OpenCyphalPicoBase-B_Paste.gbp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]
2023-08-09 corrected BOM
    [OpenCyphalPicoBase.csv, OpenCyphalPicoBase.kicad_sch]
2023-08-11 updated images and schematic pdf
    [OpenCyphalPicoBase.kicad_sch, mcp2515.kicad_sch]
2023-09-21 renamed files
    [CyphalPicoBase-CAN-B_Cu.gbl, CyphalPicoBase-CAN-B_Mask.gbs, CyphalPicoBase-CAN-B_Paste.gbp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]
2023-09-21 updated labels in schematic, updated pdf and images
    [CyphalPicoBase-CAN.kicad_pcb, CyphalPicoBase-CAN.kicad_sch]
2023-09-21 updated gerber files
    [CyphalPicoBase-CAN-B_Cu.gbl, CyphalPicoBase-CAN-B_Mask.gbs, CyphalPicoBase-CAN-B_Paste.gbp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]
2023-09-21 added pdf with dimension
    [CyphalPicoBase-CAN.kicad_pcb]
2023-09-21 updated pdf with dimension
    [CyphalPicoBase-CAN.kicad_pcb]
2023-11-18 updated enclosure top, added cutout for neopixel connector, made cut into standoff near serial connector
    [enclosure-top.stl, enclosure.FCStd]
2023-11-19 updated step file of PCB, added JST conectors
    [CyphalPicoBase-CAN.kicad_pcb, CyphalPicoBase-CAN.kicad_sch]
2023-11-19 reworked enclosure top
    [enclosure-top.stl, enclosure.FCStd]
2023-11-20 added cut out for capacitor
    [enclosure-top.stl, enclosure.FCStd]
2023-11-20 added image with connectors
2023-11-21 added connector housings to the 3d model, increased hole for serial connector
    [enclosure-bottom.stl, enclosure.FCStd]
